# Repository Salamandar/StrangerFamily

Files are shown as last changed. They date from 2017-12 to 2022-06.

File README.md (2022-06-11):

# StrangerFamily

A Stranger Things-inspired illuminated alphabet, based on a raspberrypi zero and ws2812B led strips.
strangerthings-alphabet-wall-1568829179

## Project structure

* pcb: A RaspberryPi Zero kind-of-HAT with power + LED connectors + level shifter.
* pyStranger: a Python3 project for displaying sentences from a file and/or a keyboard
* StrangerPi: CustomPiOS-based project to generate a raspberry pi imae
* arduinoSerialPixel: experimental "bridge" between raspberry pi and ws2812 leds.

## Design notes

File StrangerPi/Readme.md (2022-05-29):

# Stranger Pi based on CustomPiOS

## Preparation

```
yay -S manjaro-qemu-arm-static qemu-arm-static-bin
sudo systemctl restart systemd-binfmt
```

## Build

Just run:

```bash
sudo GET_IMAGE=1 src/build_dist
```

And on the next runs, to prevent re-downloading the image, do NOT set GET_IMAGE.

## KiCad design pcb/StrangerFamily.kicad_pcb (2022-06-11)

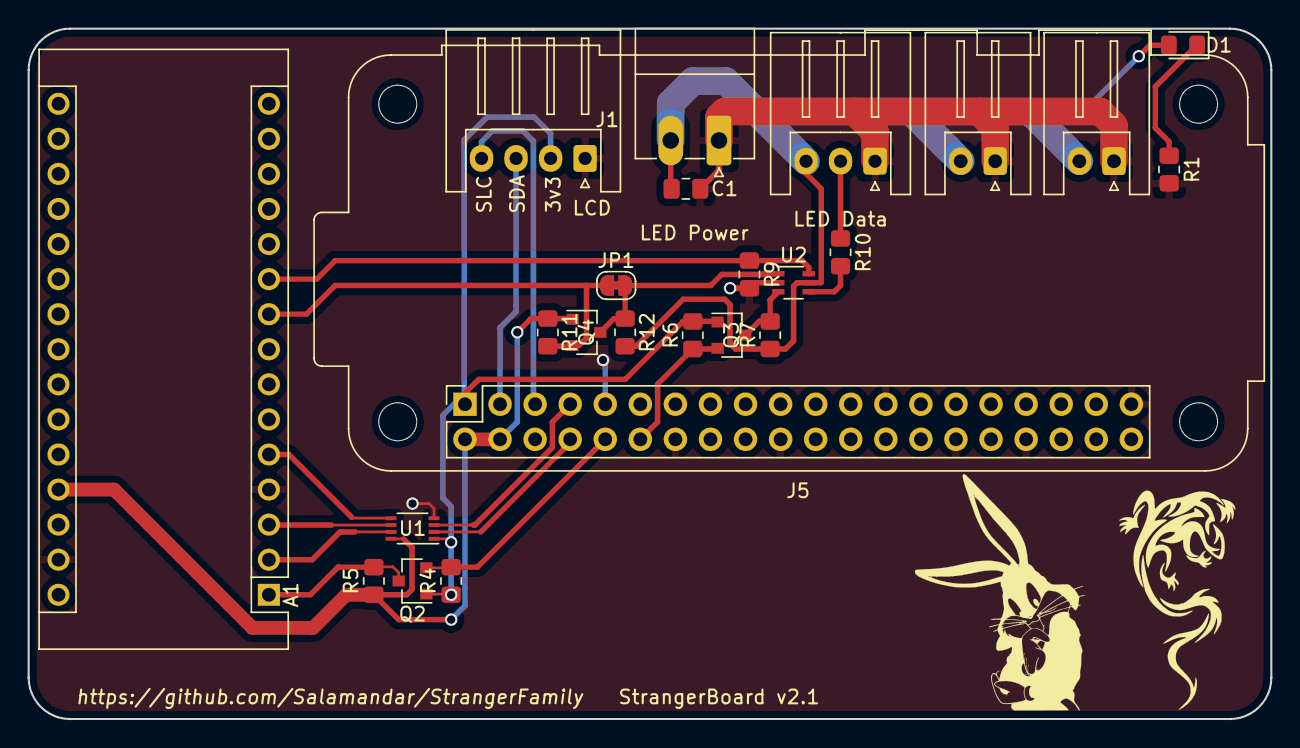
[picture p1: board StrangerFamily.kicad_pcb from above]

Board: 2 copper layers, 90.0 x 50.0 mm, 24 parts (0 on the bottom side), 21 nets.

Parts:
A1: Arduino_Nano_v3.x; Arduino_Nano
C1: C; C_0805_2012Metric_Pad1.18x1.45mm_HandSolder
D1: D; D_0805_2012Metric_Pad1.15x1.40mm_HandSolder
J1: LCD_Conn; JST_XH_S4B-XH-A_1x04_P2.50mm_Horizontal
J2: Power_LEDs; PhoenixContact_MC_1,5_2-G-3.5_1x02_P3.50mm_Horizontal
J3: Output_LED; JST_XH_S3B-XH-A_1x03_P2.50mm_Horizontal
J4, J6: LED_Out2; JST_XH_S2B-XH-A_1x02_P2.50mm_Horizontal
J5: Raspberry_Pi_zero; Raspberry_Pi_Zero_Socketed_THT_FaceDown_MountingHoles
JP1: Jumper; SolderJumper-2_P1.3mm_Bridged_RoundedPad1.0x1.5mm
Q2, Q3, Q4: BSS138; SOT-23
R1: R; R_0805_2012Metric_Pad1.20x1.40mm_HandSolder
R4, R5, R6, R7, R9, R11, R12: 10k; R_0805_2012Metric_Pad1.20x1.40mm_HandSolder
R10: 470; R_0805_2012Metric_Pad1.20x1.40mm_HandSolder
U1: 74LVC2T45DC; VSSOP-8_2.3x2mm_P0.5mm
U2: 74LVC1G3157; Texas_R-PDSO-G6

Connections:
+3V3: A1.17, J1.2, J5.1, Q2.1, Q3.1, R4.1, R6.1, U1.1
+5V: A1.27, J5.2, J5.4, Q4.1, R5.1, R11.1, U1.8
/Arduino_is_out: A1.10, R9.1, U2.6
/Arduino_out: A1.9, JP1.2, Q4.2, R11.2
/Arduino_out_VDD: JP1.1, Q4.3, R12.2, U2.1
/LCD_SDA: J1.3, J5.3
/LCD_SLC: J1.4, J5.5
/Nano_RX: A1.2, U1.7
/Nano_TX: A1.1, Q2.3, R5.2
/Nano_~Reset: A1.3, U1.6
/PWM0: J5.12, Q3.2, R6.2
/PWM0_VDD: Q3.3, R7.2, U2.3
/RPi_Nano_~Reset: J5.7, U1.3
/RPi_RX: J5.10, Q2.2, R4.2
/RPi_TX: J5.8, U1.2
/RX_enable: A1.5, U1.5
GND: A1.4, A1.29, C1.1, J1.1, J2.1, J3.1, J4.1, J5.6, J5.9, J5.14, J5.20, J5.25, J5.30, J5.34, J5.39, J6.1, R1.2, R9.2, U1.4, U2.2
unnamed: D1.1, R1.1
unnamed: J3.2, R10.1
unnamed: R10.2, U2.4
VCC: C1.2, D1.2, J2.2, J3.3, J4.2, J6.2, R7.1, R12.1, U2.5

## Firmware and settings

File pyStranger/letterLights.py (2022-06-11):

#!/bin/env python3

import os,sys,signal
import time,argparse,random,colorsys
from collections import OrderedDict

import database

try:
    from neopixel import *
    from rpi_ws281x import *
    print('neopixel found')
except ImportError:
    print('neopixel not found!')
    # Fake neopixel module
    import serial
    import base64

    class ws():
        WS2811_STRIP_GRB = 0
        WS2811_STRIP_RGB = 1

    class Color():
        def __init__(self, r,g,b):
            self.R = r
            self.G = g
            self.B = b
            pass

    class Adafruit_NeoPixel():
        def __init__(self, num, pin, freq_hz=800000, dma=5, invert=False,
            brightness=255, channel=0, strip_type=ws.WS2811_STRIP_RGB):
            print('Initialization serial')
            self.ser = serial.Serial(
            port='/dev/ttyUSB0',
            baudrate = 115200,
            parity=serial.PARITY_NONE,
            stopbits=serial.STOPBITS_ONE,
            bytesize=serial.EIGHTBITS,
            timeout=1
            )
            time.sleep(2)
        def _cleanup(self):
            pass
        def begin(self):
            pass
        def show(self):
            pass
        def setPixelColor(self, n, color):
            self.setPixelColorRGB(n, color.R, color.G, color.B)
        def setPixelColorRGB(self, n, red, green, blue, white = 0):
            print('setpixelcolor {} {} {} {}'.format(n, red, green, blue))
            buffer = bytearray()
            buffer.append(red)
            buffer.append(green)
            buffer.append(blue)
            n_b64 = base64.b64encode(str(n).encode())
            self.ser.write('>'.encode())
            self.ser.write(str(n).encode())
            self.ser.write(':'.encode())
            self.ser.write(base64.b64encode(buffer))
            self.ser.write('='.encode())
            # while self.ser.in_waiting:
            #     print(self.ser.readline())
        def setBrightness(self, brightness):
            pass
        def getPixels(self):
            pass
        def numPixels(self):
            return LED_COUNT
            pass
        def getPixelColor(self, n):
            pass


def signal_handler(signal, frame):
    colorWipe(strip, Color(0,0,0))
    sys.exit(0)

def opt_parse():
    parser = argparse.ArgumentParser()
    parser.add_argument('-c', action='store_true', help='clear the display on exit')
    args = parser.parse_args()
    if args.c:
        signal.signal(signal.SIGINT, signal_handler)

# LED strip configuration:
LED_PIN        = 18      # GPIO pin connected to the pixels (18 uses PWM!).
#LED_PIN        = 10      # GPIO pin connected to the pixels (10 uses SPI /dev/spidev0.0).
LED_FREQ_HZ    = 800000  # LED signal frequency in hertz (usually 800khz)
LED_DMA        = 5       # DMA channel to use for generating signal (try 5)
LED_BRIGHTNESS = 255     # Set to 0 for darkest and 255 for brightest
LED_INVERT     = False   # True to invert the signal (when using NPN transistor level shift)
LED_CHANNEL    = 0       # set to '1' for GPIOs 13, 19, 41, 45 or 53
LED_STRIP      = ws.WS2811_STRIP_GRB   # Strip type and colour ordering

# Letters configuration :number of lights for each letter
# USAGE (for example with B):
#   position = ord('B') - ord('A')
#   2 = lightsList[position]
#   1 = Sum of previous positions
#         for j in range(1, 2):
#            strip.setPixelColor(j, color)
letters = OrderedDict([
    ('A', 15),
    ('B', 11),
    ('C',  9),
    ('D', 12),
    ('E', 13),
    ('F',  9),
    ('G', 10),
    ('H', 12),
    ('I',  8),
    ('J', 12),
    ('K', 11),
    ('L', 11),
    ('M', 18),
    ('N', 11),
    ('O',  9),
    ('P', 12),
    ('Q', 11),
    ('R', 11),
    ('S', 10),
    ('T', 11),
    ('U',  9),
    ('V', 11),
    ('W', 17),
    ('X', 13),
    ('Y', 13),
    ('Z', 15),
])

# For Neopixel
LED_COUNT = sum(list(letters.values())

def getLetterPositions(letter):
    letterPositions = [0, 0]

    if letter not in letters.keys():
       return letterPositions

    tableLetterPosition = list(letters.keys()).index(letter)
    ledLetterPosition = 0

    # print(tableLetterPosition);

    for key in letters:
        if key != letter:
            ledLetterPosition += letters[key]
        else:
            break

    letterPositions[0] = ledLetterPosition
    letterPositions[1] = letters[letter]
    print(letter)
    # print(letterPositions)
    return letterPositions

def hsv_to_neopixel_color(h, s, v):
    (r, g, b) = colorsys.hsv_to_rgb(h, s, v)
    return Color(int(255 * r), int(255 * g), int(255 * b))


class LetterLights():
    def __init__(self, database, lcdscreen):
        self.stringdb = database
        self.lcdscreen = lcdscreen
        # Create NeoPixel object with appropriate configuration.
        self.strip = Adafruit_NeoPixel(LED_COUNT, LED_PIN, LED_FREQ_HZ, LED_DMA, LED_INVERT, LED_BRIGHTNESS, LED_CHANNEL, LED_STRIP)
        # Initialize the library (must be called once before other functions).
        self.strip.begin()
        self.shutoffLights()
        self.animationsList = [func for func in dir(LetterLights) if callable(getattr(LetterLights, func)) and func.startswith('animation')]
        self.setAnimation('Smooth')


    def shutoffLights(self):
        for i in range(self.strip.numPixels()):
            self.strip.setPixelColor(i, Color(0,0,0))
        self.strip.show()

    def setAnimation(self, name):
        self.animationMethod = getattr(self, 'animation' + name)

    def setRandAnimation(self):
        pass

    def animate(self, letterPositions):
        for color in self.animationMethod():
            for j in range(letterPositions[0], letterPositions[0]+letterPositions[1]):
                self.strip.setPixelColor(j, color)
            self.strip.show()
        self.shutoffLights()

    def animationLightning(self):
        color = Color(255, 255, 255)
        random.seed(os.urandom(5))
        timeLeft = 500
        i = 0

        if letterPositions[1] == 0:
            time.sleep(timeLeft/1000.0)
            return

        # So we'll do calculations in HSV, then convert to RGB
        hue = random.uniform(0, 1)
        # Detected on duration of led ON
        value = 0
        saturation = 0.9

        # i-eme cycle
        while timeLeft>0:
            wait_ms = random.randint(0, timeLeft)

            if i % 2 == 0:
                value = 0
            else:
                value = wait_ms / (wait_ms + 100)

            yield hsv_to_neopixel_color(hue, saturation, value)

            time.sleep(wait_ms/1000.0)
            timeLeft = timeLeft-wait_ms
            i += 1
        return

    def animationOnOff(self):
        timeLeft = 500
        hue = random.uniform(0, 1)
        saturation = 0.9
        yield hsv_to_neopixel_color(hue, saturation, value)
        time.sleep(timeLeft/1000.0)
        return

    def animationSmooth(self):
        timeTotal = 200.0 / 1000.0
        timeRamp  = 50.0 / 1000.0
        timeLevel = timeTotal - 2 * timeRamp

        hue = random.uniform(0, 1)
        saturation = 0.9

        steps = 50
        for k in range(1, steps + 1):
            v = k * 255 / steps
            value = v / (v + 100)
            yield hsv_to_neopixel_color(hue, saturation, value)
            time.sleep(timeRamp / steps)

        v = 255
        value = v / (v + 100)
        yield hsv_to_neopixel_color(hue, saturation, value)
        time.sleep(timeLevel)

        for k in range(1, steps + 1):
            v = (steps-k) * 255 / steps
            value = v / (v + 100)
            yield hsv_to_neopixel_color(hue, saturation, value)
            time.sleep(timeRamp / steps)

        return

    def chenillard(self):
        timeFixed  = 5.0 / 1000.0
        hue = random.uniform(0, 1)
        saturation = 0.9
        sizeChenillard = 10

        self.shutoffLights()
        for i in range(self.strip.numPixels() + sizeChenillard):

            hue += 1./self.strip.numPixels()
            if hue > 1:
                hue -= 1

            value = 1
            for j in range(sizeChenillard):
                if i-j >= 0:
                    self.strip.setPixelColor(i-j, hsv_to_neopixel_color(hue, saturation, value))
                    value = value/2
            if i-j-1 >= 0:
                self.strip.setPixelColor(i-j-1, Color(0,0,0))

            self.strip.show()
            time.sleep(timeFixed)

    def onePrint(self):
        sentence = self.stringdb.getRandSentence()
        self.lcdscreen.setLedsText(sentence.text)
        sequenceOfAlphabets = list(sentence.text.upper())

        total = len(sequenceOfAlphabets)
        i = 0
        for letter in sequenceOfAlphabets:
            i+=1
            self.lcdscreen.setLedsProgression(100*i/total)
            self.animate(getLetterPositions(letter))
            time.sleep(0.1)
            if self.stringdb.should_echo_last_temp:
                break



# Dummy i2c class
class Nop(object):
    def nop(*args, **kw): pass
    def __getattr__(self, _): return self.nop


if __name__ == '__main__':
    # Process arguments
    opt_parse()

    stringdb = database.StrangerDatabase()
    letterLights = LetterLights(stringdb, Nop())

    # letterLights.onePrint()
    letterLights.chenillard()

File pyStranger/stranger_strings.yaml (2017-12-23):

sentences:
  - text: 'Mornings are for coffee and contemplation'
    speed: 1
  - text: 'If anyone asks where I am, Ive left the country'
    speed: 1
  - text: 'I dont care if anyone believes me'
    speed: 1
  - text: 'Mouth breather'
    speed: 1
  - text: 'Eggos'
    speed: 1

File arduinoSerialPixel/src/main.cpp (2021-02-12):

#include "leds.hpp"
#include "serial.hpp"

#include "Arduino.h"

LEDStrip* strip;
LEDsReceiver* uart_receiver;

const int ledcount = 24;
const unsigned int baudrate = 115200;

void setup()
{
    LEDStrip::set_arduino_is_out(true);

    strip = new LEDStrip(ledcount);
    uart_receiver = new LEDsReceiver(ledcount, baudrate);

    // Start Sequence
    strip->setAll(strip->RED);
    delay(500);
    strip->setAll(strip->BLUE);
    delay(500);
    strip->setAll(strip->GREEN);
    delay(500);
    strip->setAll(strip->STARTCOLOR);
    delay(200);
}


void loop()
{
    if (uart_receiver->handle()) {
        auto led = uart_receiver->getLastLEDId();
        auto color = uart_receiver->getLastColor();
        Serial.print("recv: led ");
        Serial.print(led, DEC);
        Serial.print(" color : ");
        Serial.print(color, HEX);
        Serial.println();

        strip->set(led, color);

        if (uart_receiver->should_show()) {
            Serial.println("showing leds !");
            strip->commit();
        }
    }
}

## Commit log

2017-12-21 mount bind the repository inside the chroot
2017-12-21 mount bind is not that great. Just copying, and as read-only.
2017-12-21 Python3 : fix indent, print()
    [letterLights.py]
2017-12-21 Add some to python, thread logic.
2017-12-22 Adding all leds numbers by letter
2017-12-22 Fix imports ; Add dummy Neopixel lib if not found (not on Raspi)
    [letterLights.py]
2017-12-22 Static init of list ; fix py3
    [letterLights.py]
2017-12-22 Add leds thread.
2017-12-23 Add i2c lcd implementation
2017-12-23 Add dummy version of i2c
2017-12-23 Fix: if no db found.
    [database.py]
2017-12-23 Add do-not-crash-on-i2c-fail test.
2017-12-24 qwerty, correct input device for py
    [entry.py]
2017-12-24 Fix address for screen
    [i2c_lib.py]
2017-12-24 Add main for test ; fix clear().
    [screen.py]
2017-12-24 Fix led count
2017-12-24 Fix R led count
    [letterLights.py]
2017-12-25 Change leds color definition. Remove verbosity.
2017-12-25 Add animations framework
2017-12-26 Fix: backspace. Fix test. Fix clean after ok.
    [entry.py]
2017-12-26 Fix letters count, break sentence on new typed
    [letterLights.py]
2017-12-27 Fix hsv_top_neo. Fix smooth animation.
    [letterLights.py]
2017-12-27 Fix screen ? Only print keyboard text, cleanup line on print.
    [entry.py, i2c_lib.py, screen.py]
2017-12-27 Fix timing for smooth animation
    [letterLights.py]
2017-12-28 Fix : load temp on boot, set string count on boot
    [database.py, stranger_family.py]
2017-12-29 Fix tabs -> spaces. Fix call.
    [letterLights.py]
2017-12-29 Fix chenillard. Add to sentences loop.
    [letterLights.py, stranger_family.py]
2018-06-19 bash…
2018-06-19 Fix when / is not a mountpoint
2018-08-01 Add hardware, .gitignore updated.
    [StrangerFamily.kicad_pcb, StrangerFamily.sch]
2018-08-01 2 channels, cleanup
    [StrangerFamily.kicad_pcb, StrangerFamily.sch]
2018-08-23 Add LCD connector.
    [StrangerFamily.kicad_pcb, StrangerFamily.sch]
2018-08-24 Use available component on RS
    [StrangerFamily.sch]
2018-09-20 Change connector footprints (very small non critical changes)
    [StrangerFamily.kicad_pcb, StrangerFamily.sch]
2020-01-09 Add Pi and Arduino code to control Neopixel Arduino from the Pi
2020-01-10 Simplify call to the Arduino (led per led)
2020-01-13 Écriture de serial.hpp
2020-01-17 update payload to be b64 arduino reader compliant - not working
    [letterLights.py]
2020-01-17 pixel id is an integer - not working
    [letterLights.py]
2020-01-25 Add '=' in the frame sent to serial ; remove serial read
2020-07-15 v2 of hardware with rpi zero w, and arduino nano
    [NanoV3 v4.step, StrangerFamily.kicad_pcb, StrangerFamily.sch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]
2020-11-24 Reorganize arduino code
2020-11-25 Update hardware designs. This is v2 sent to prod in august 2020.
    [StrangerFamily.kicad_pcb, StrangerFamily.sch]
2020-11-25 Fix raspberry pi missing sd card slot
    [StrangerFamily.kicad_pcb, StrangerFamily.sch]
2020-12-04 Fix electronics (schematics), use new components
    [StrangerFamily.kicad_pcb, StrangerFamily.sch, level_shifter.sch]
2020-12-21 v2 : use logos, move footprints
    [NanoV3 v4.step, StrangerFamily.kicad_pcb, StrangerFamily.sch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]
2021-02-10 Add both arduino variants
2021-02-11 Reorganize repository
    [StrangerFamily.kicad_pcb, StrangerFamily.sch, level_shifter.sch]
2021-02-11 Move arduino code. Kept named as arduinoSerialPixel because it's not related to the StrangerFamily project
2021-02-12 Add arduino_is_out, change start sequence
2022-06-11 Define LED_COUNT according to the letters list. Remove one LED from A after repairs.
2022-06-11 Update kicad project version
    [StrangerFamily.kicad_pcb, StrangerFamily.kicad_sch, StrangerFamily.sch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]
